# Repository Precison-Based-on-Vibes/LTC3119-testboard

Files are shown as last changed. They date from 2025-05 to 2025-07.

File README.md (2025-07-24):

# LTC3119-testboard
LTC3119 testbord is a device build to test MPPT adaptation of this DCDC converter

## Schematic

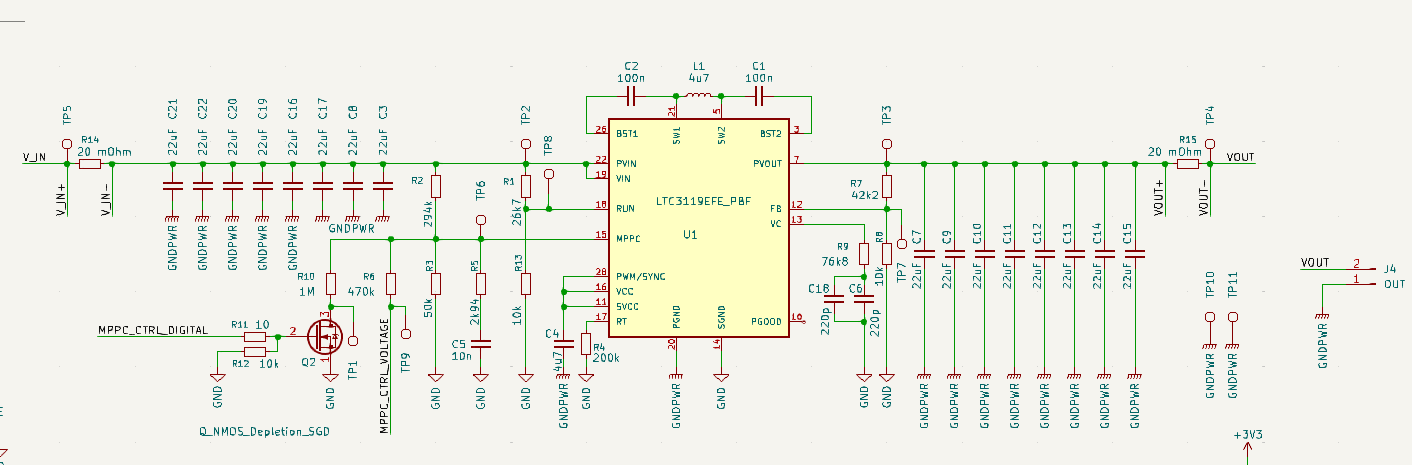
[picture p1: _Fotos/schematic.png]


## Tests Documentation

### Configuration A
- Configuration of a testbed before tests:
    - Input Capacitance: 4 x 22 uF
    - Output Capacitance: 4 x 22uF
    - MPPC Compensation: 10nF, 1k47 Ohm (C5, R5)
    - Evrything else: same as in design files

- Nominal operation - Output noice mesurment (probed directly with coaxial cable with 50 ohm terminantion on oscilosope)
    - No external load (PSU not current limited)  
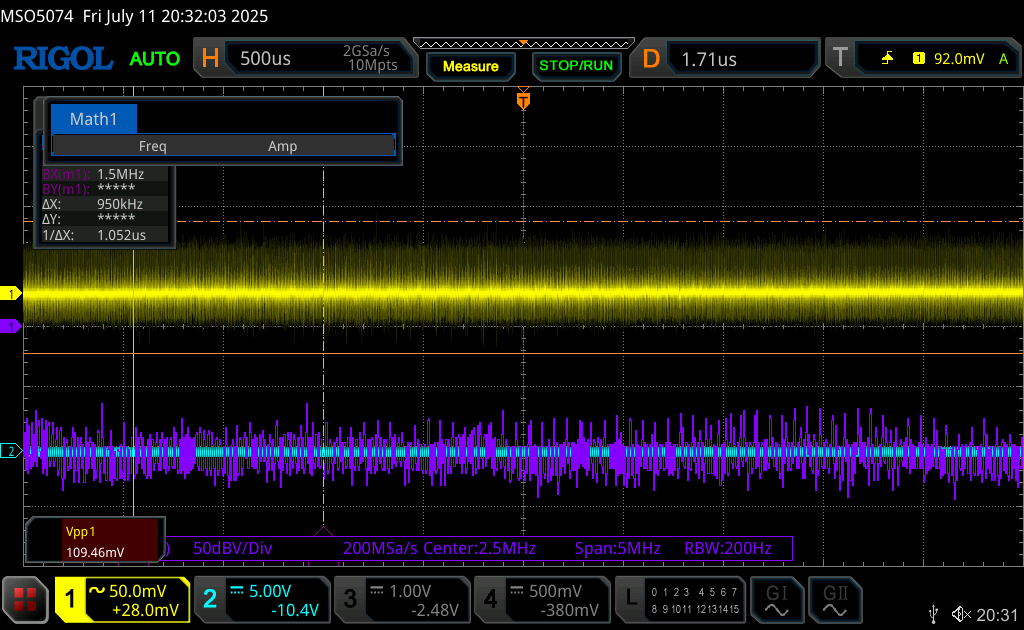
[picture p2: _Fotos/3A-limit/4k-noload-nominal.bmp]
    
    - External load 1A (PSU not current limited)  
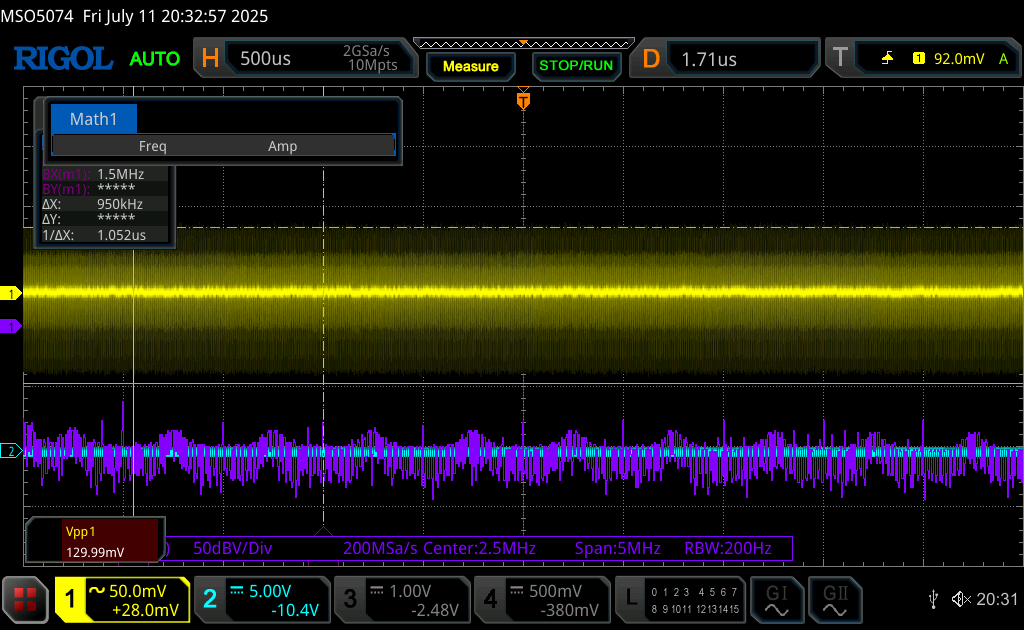
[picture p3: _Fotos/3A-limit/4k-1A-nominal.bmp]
    
    - External load 2A (PSU not current limited)  
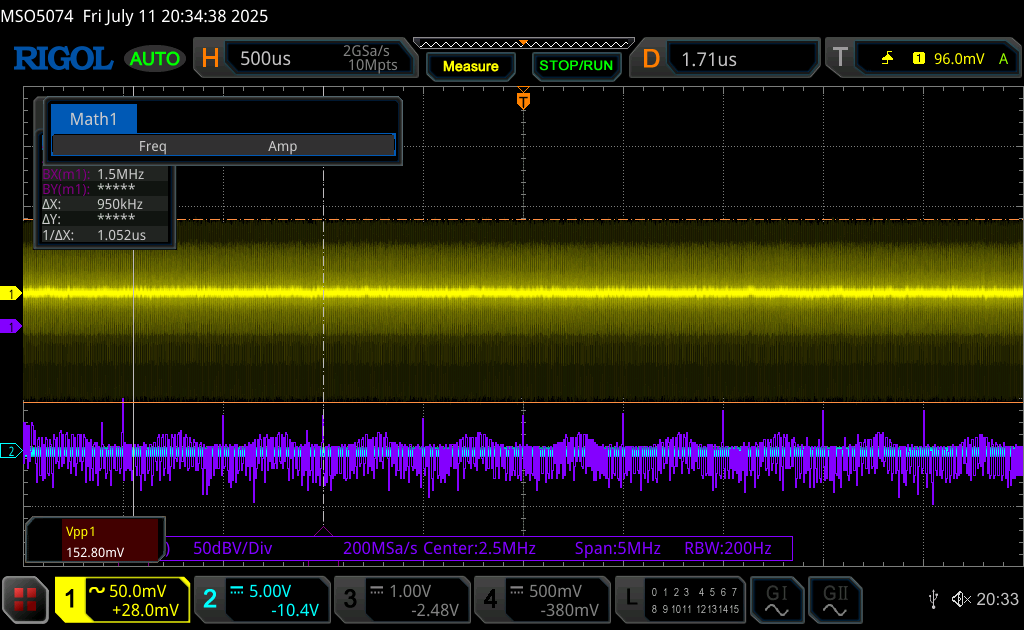
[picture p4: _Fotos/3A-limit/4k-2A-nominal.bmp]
    
    - External load 3A (PSU not current limited)  
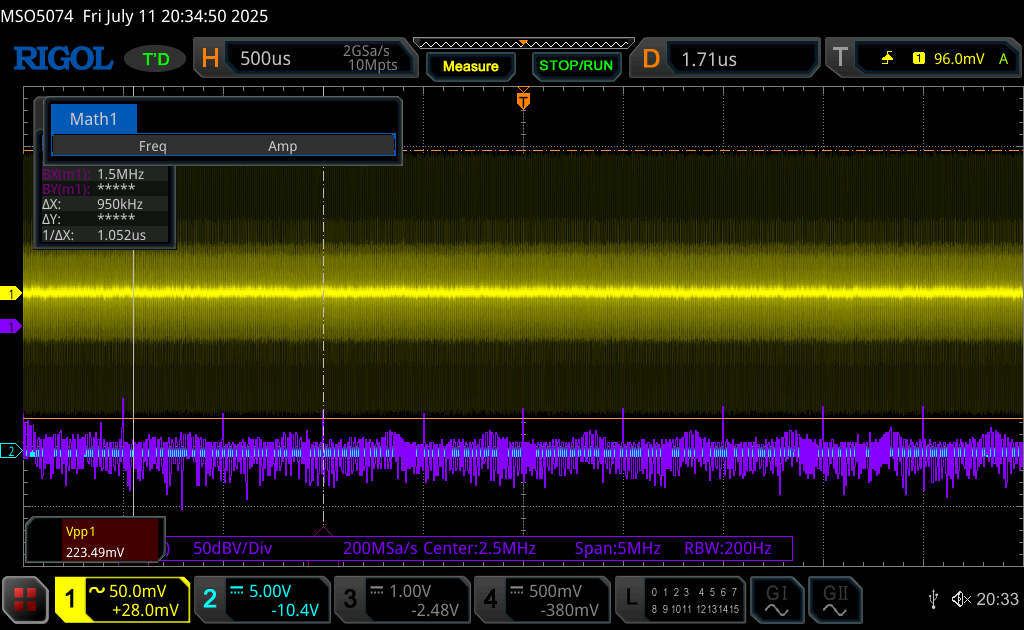
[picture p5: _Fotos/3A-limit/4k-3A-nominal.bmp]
    

- MPPC Test - Output Voltage and noice mesurment (probed directly with coaxial cable with 50 ohm terminantion on oscilosope)
    - External load 1A - Messured output voltage - 4.09 V (voltage messured on electronic load, not compensated for voltage drop on cables) (PSU limited to 1A - not active)  
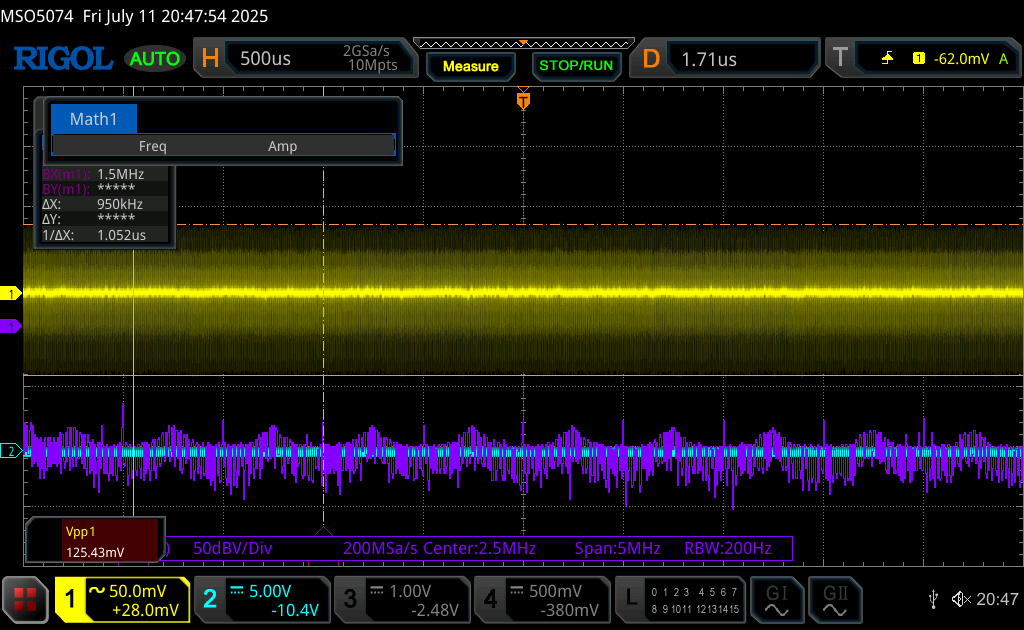
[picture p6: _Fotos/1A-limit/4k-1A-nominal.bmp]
    
    - External load 1A5 - Messured output voltage - 3.13 V (voltage messured on electronic load, not compensated for voltage drop on cables) (PSU limited to 1A - active)   
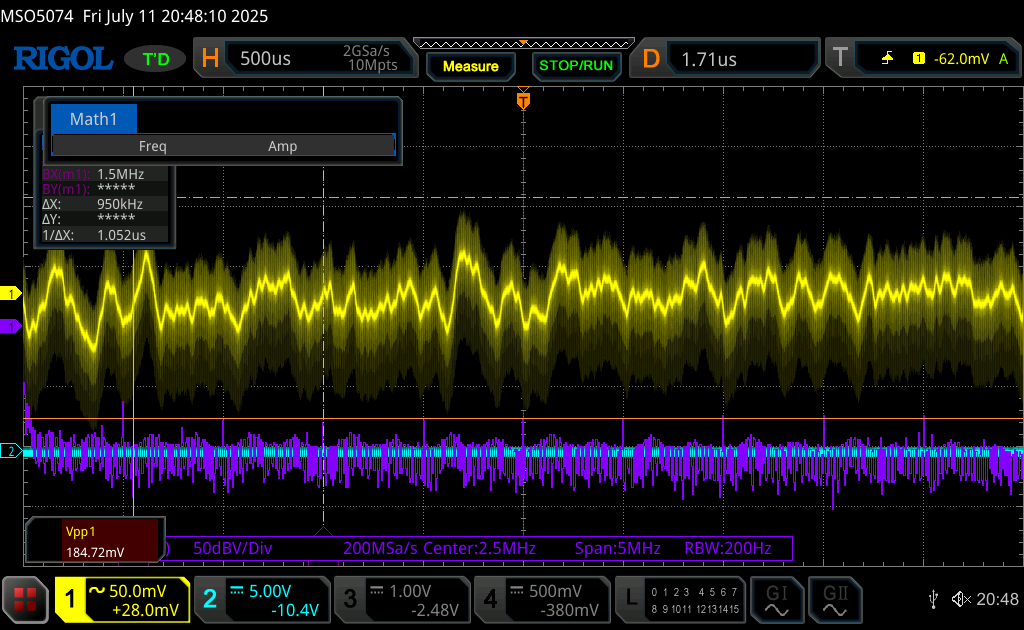
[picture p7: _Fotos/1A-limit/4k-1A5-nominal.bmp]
    
    - External load 2A - Messured output voltage - 2.25 V (voltage messured on electronic load, not compensated for voltage drop on cables) (PSU limited to 1A - active)  
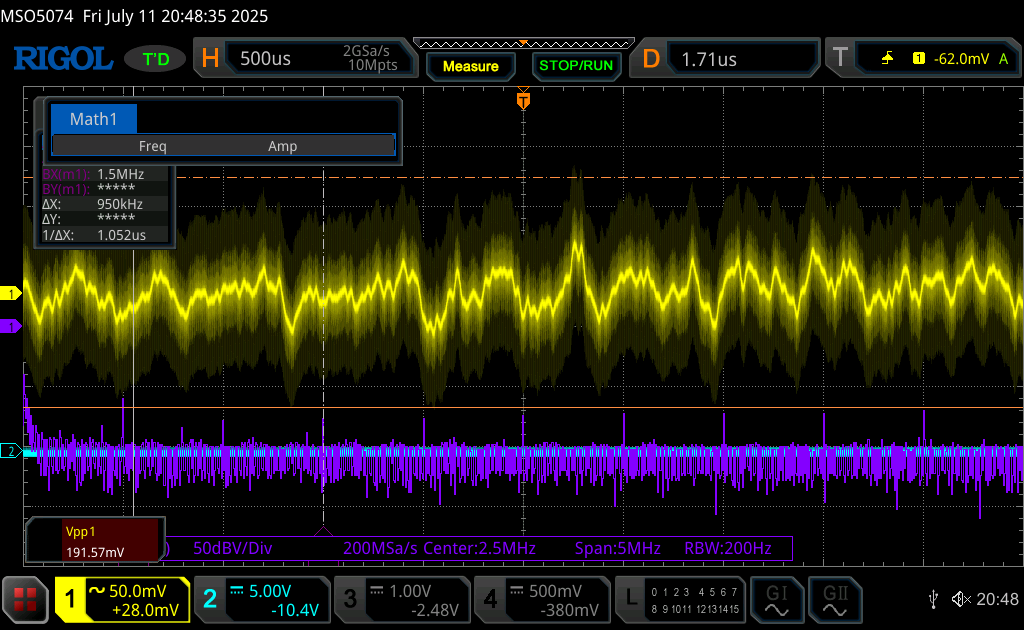
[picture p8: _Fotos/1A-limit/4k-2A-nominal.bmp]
    
    - External load 1A3 - Messured output voltage - 3.63 V (voltage messured on electronic load, not compensated for voltage drop on cables) (PSU limited to 1A - active) (IMPORTANT: FFT for low frequency noice)
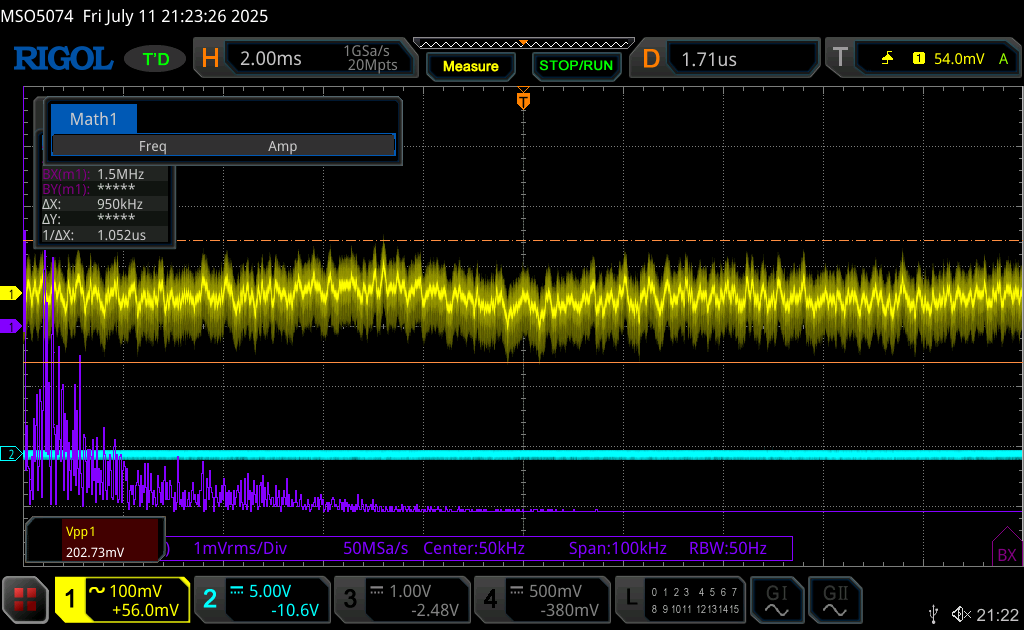
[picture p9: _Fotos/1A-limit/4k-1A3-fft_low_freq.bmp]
    

- MPPC Input voltage regulation setpoint vs control voltage  
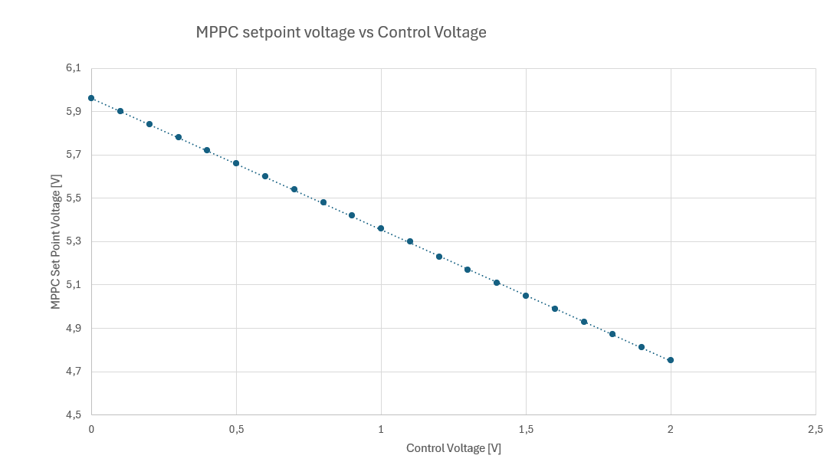
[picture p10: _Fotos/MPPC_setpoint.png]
  

### Configuration B
- Configuration of a tesbed before test:    
    - Input Capacitance: 4 x 22 uF
    - Output Capacitance: 4 x 22uF
    - MPPC Set point Components: 226k Ohm, 1M25 Ohm, 470k Ohm (R3, R2, R6)
    - MPPC Compensation: 2.2nF, 6k8 Ohm (C5, R5)
    - Evrything else: same as in design files

-  MPPC Test - Noice mesurment (probed directly with coaxial cable with 50 ohm terminantion on oscilosope)
   - External load 1A (PSU limited to 1A - not active)  
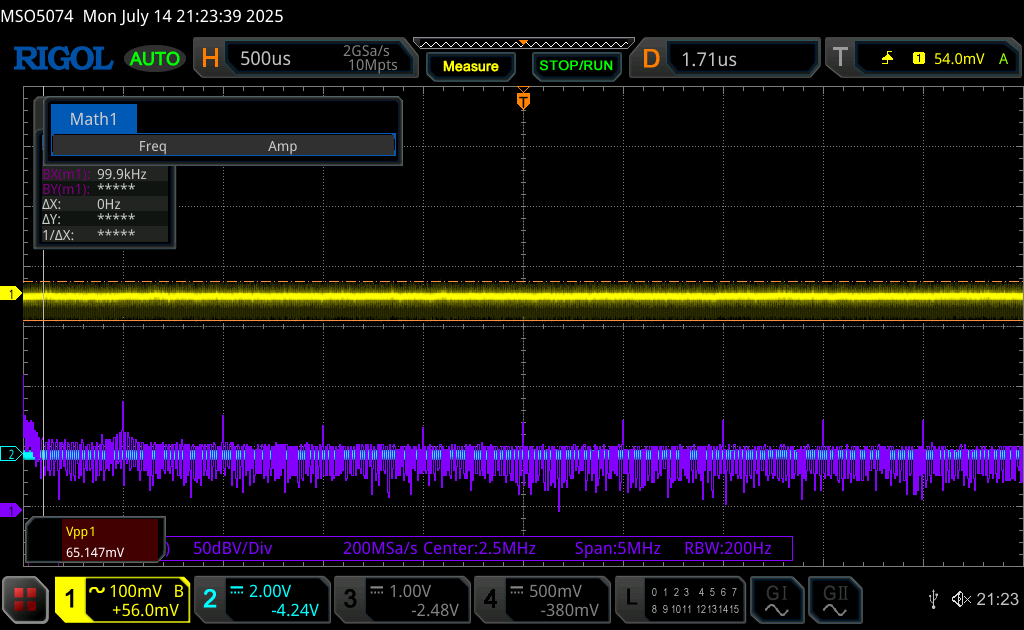
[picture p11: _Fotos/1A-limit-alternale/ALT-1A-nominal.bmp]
    
    - External load 1A5 (PSU limited to 1A - active)   
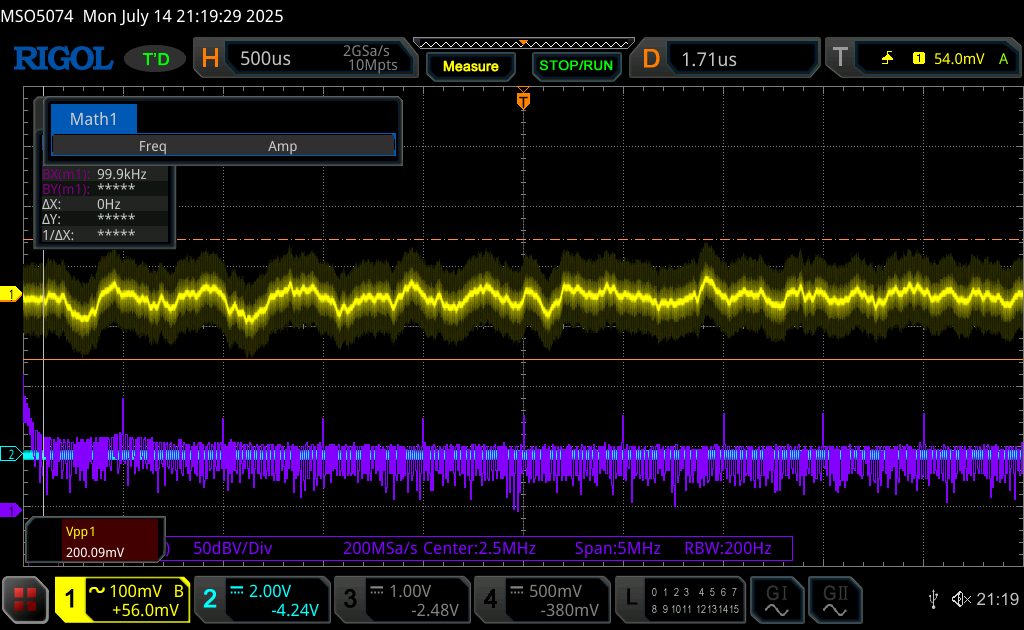
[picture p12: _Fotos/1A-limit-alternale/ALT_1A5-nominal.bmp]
    
    - External load 2A (PSU limited to 1A - active)  
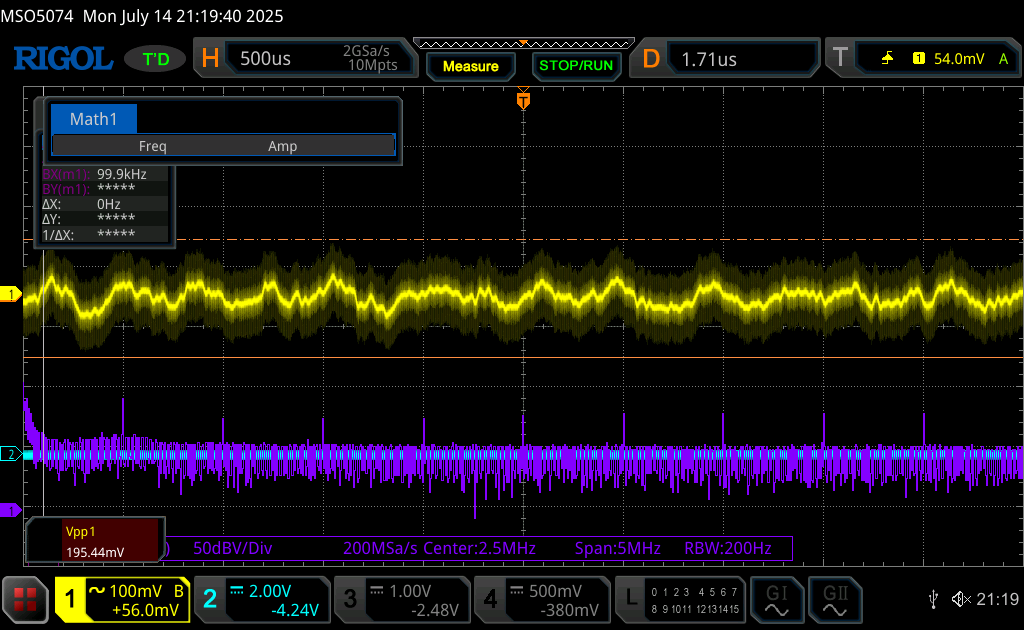
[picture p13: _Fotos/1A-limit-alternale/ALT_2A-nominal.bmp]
    
    - External load 1A3 - Messured output voltage - 3.63 V (PSU limited to 1A - active) (IMPORTANT: FFT for low frequency noice)
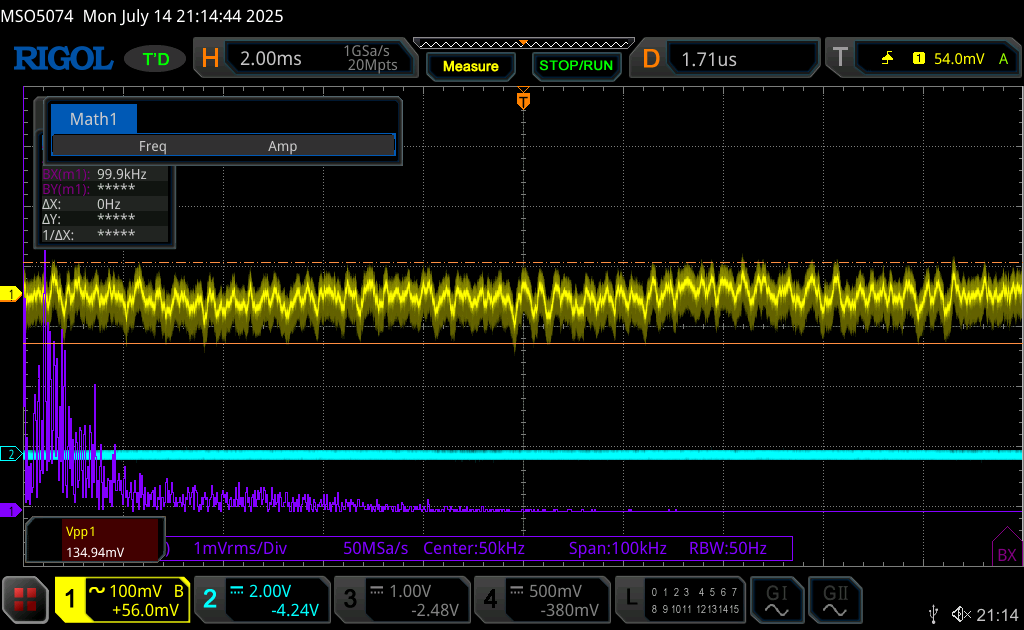
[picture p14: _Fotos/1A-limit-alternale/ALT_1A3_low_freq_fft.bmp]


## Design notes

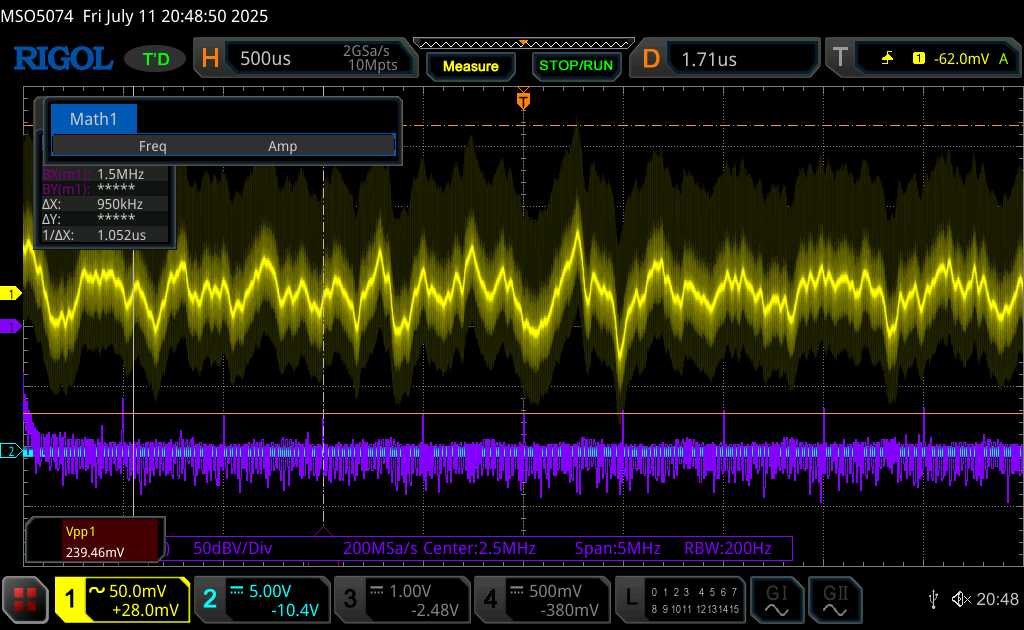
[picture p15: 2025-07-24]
_Fotos/1A-limit/4k-2A5-nominal.bmp

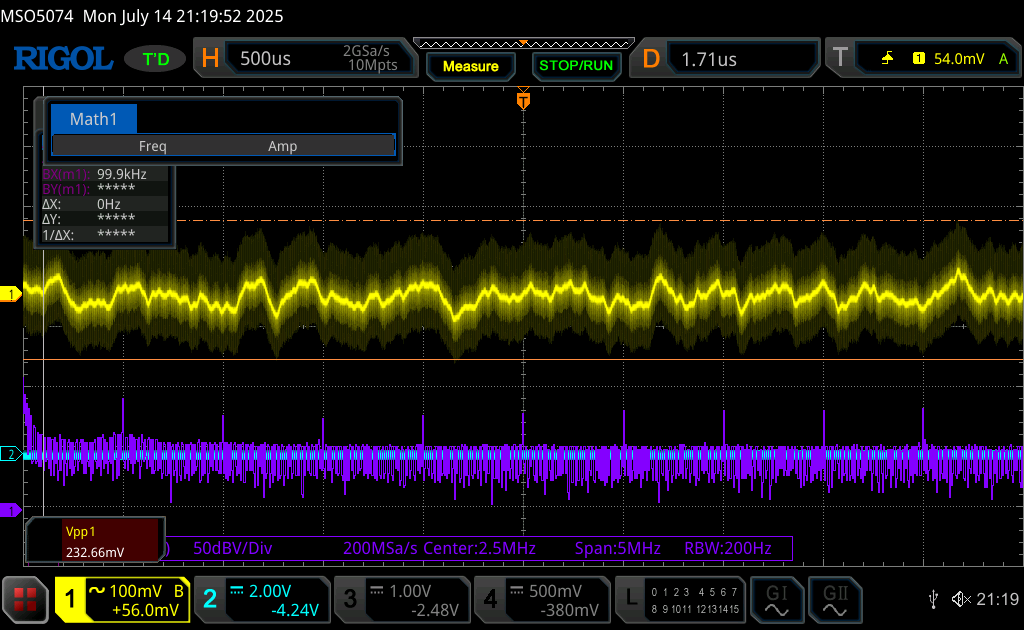
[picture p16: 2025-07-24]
_Fotos/1A-limit-alternale/ALT-2A5-nominal.bmp

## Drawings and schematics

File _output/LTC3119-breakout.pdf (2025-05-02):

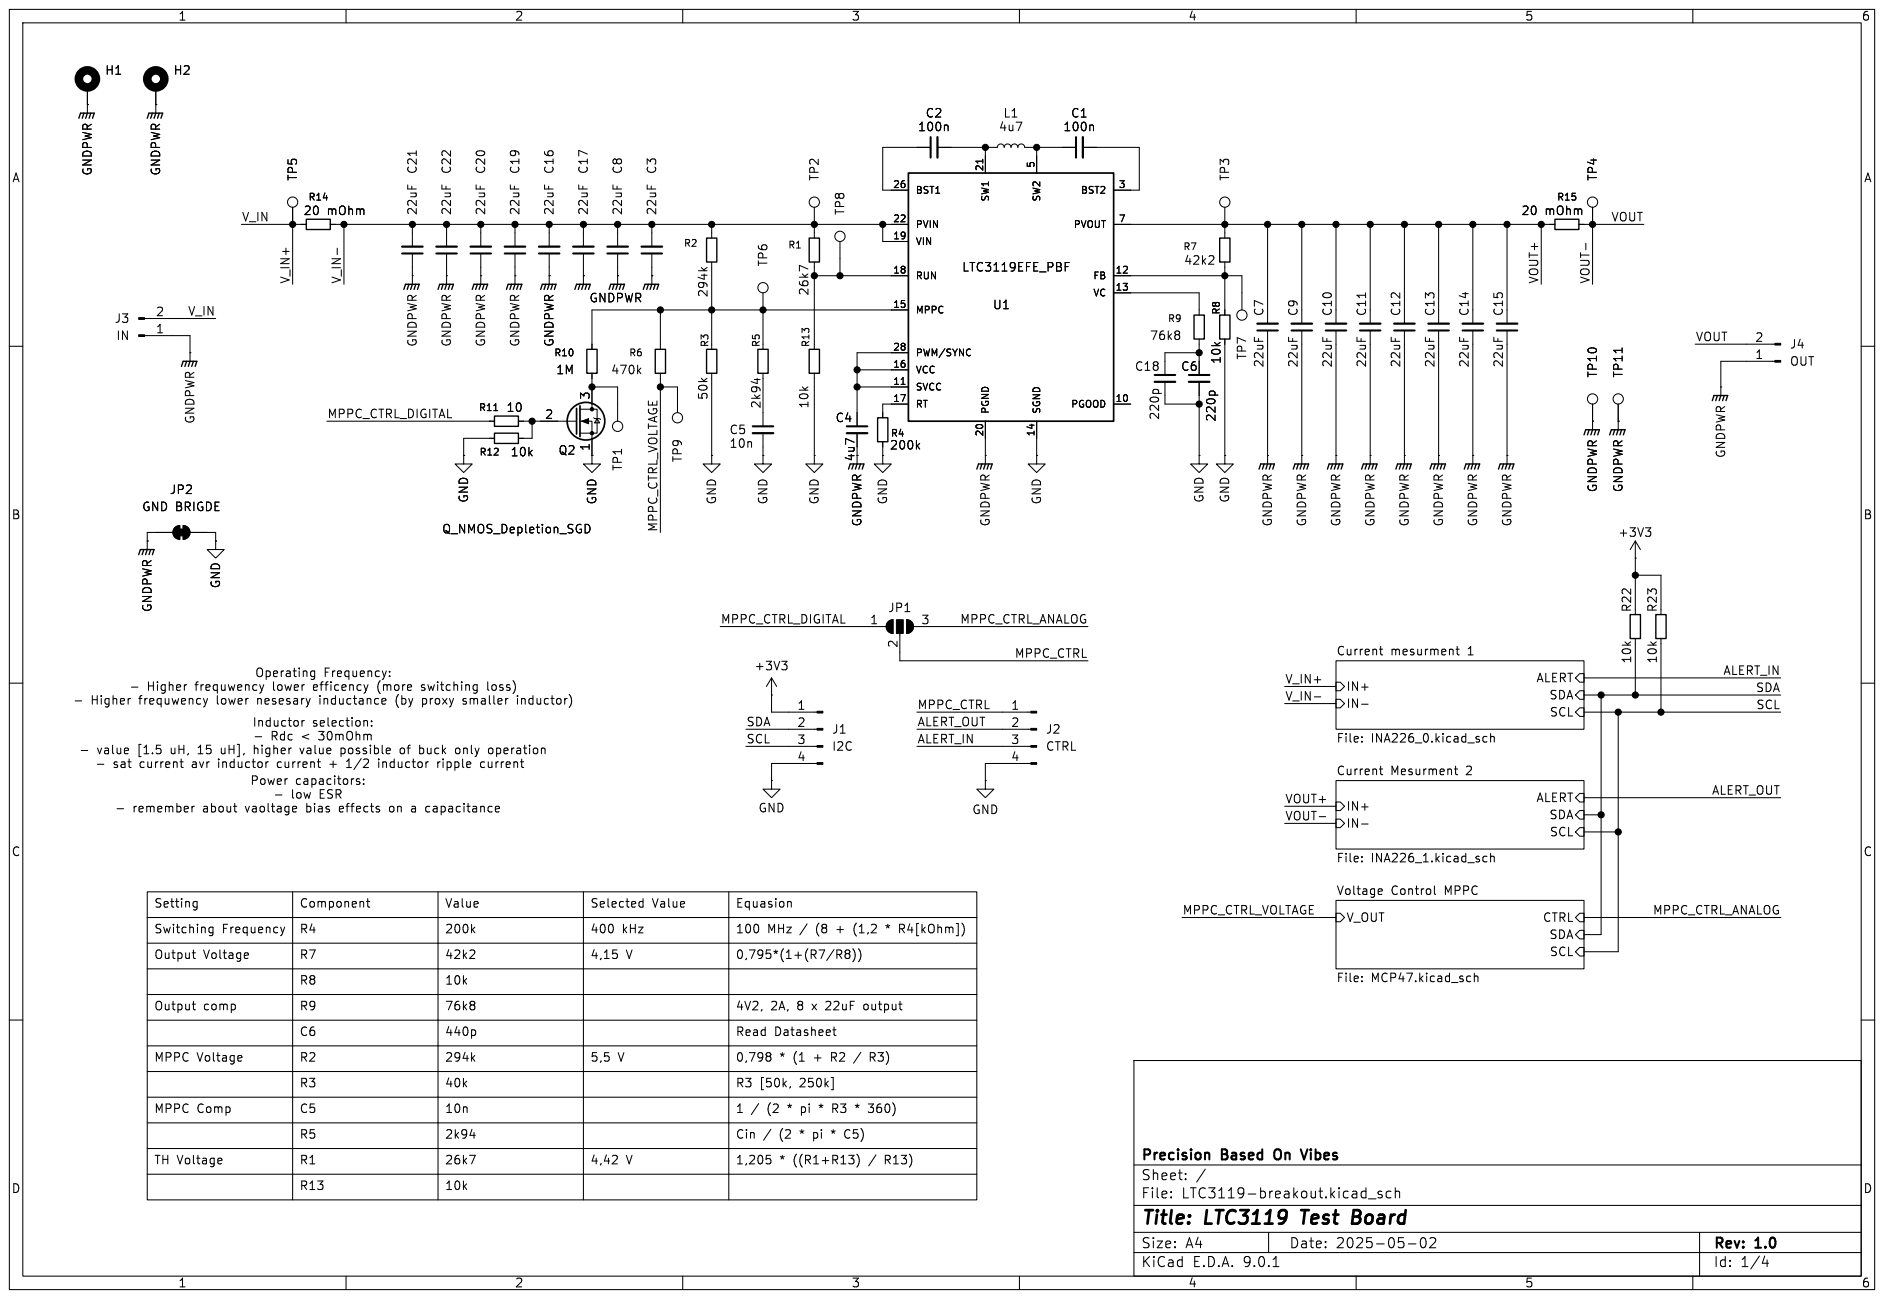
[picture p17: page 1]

5 SGND 14 BST2 3 PVOUT 7 FB 12 VC 13 PGOOD 10 C2

5 SGND 14 BST2 3 PVOUT 7 FB 12 VC 13 PGOOD 10 U1

Id: 1/4 Title: LTC3119 Test Board

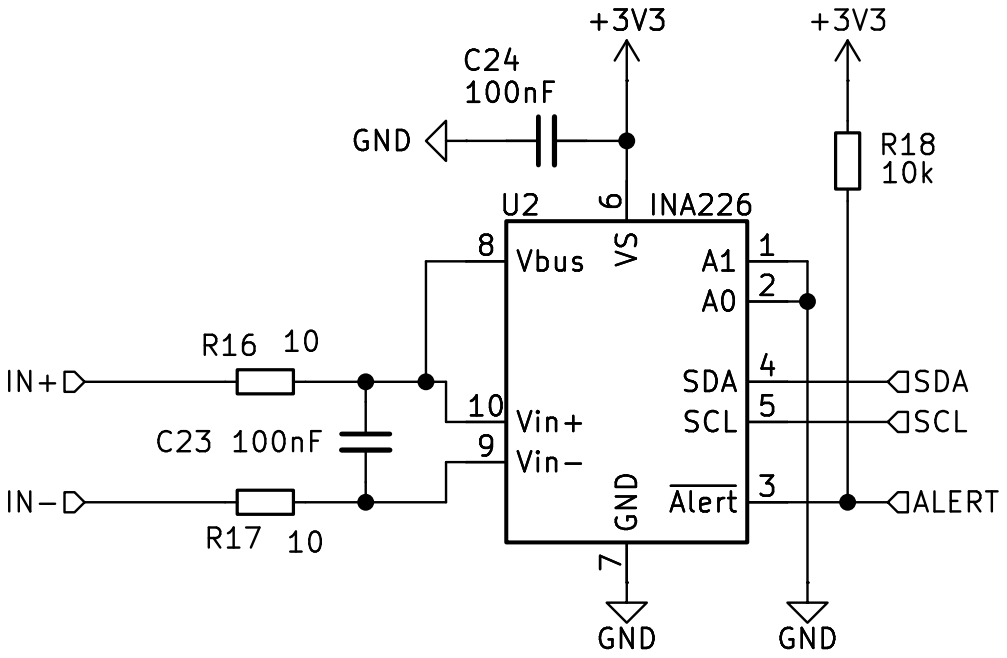
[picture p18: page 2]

7 A1 1 A0 2 SDA 4 SCL 5 ~{Alert}3 U2 INA226 +3V3 C23 100nF R17 10 R16 10 GND

7 A1 1 A0 2 SDA 4 SCL 5 ~{Alert}3 GND GND GND

Id: 2/4 Title: LTC3119 Test Board

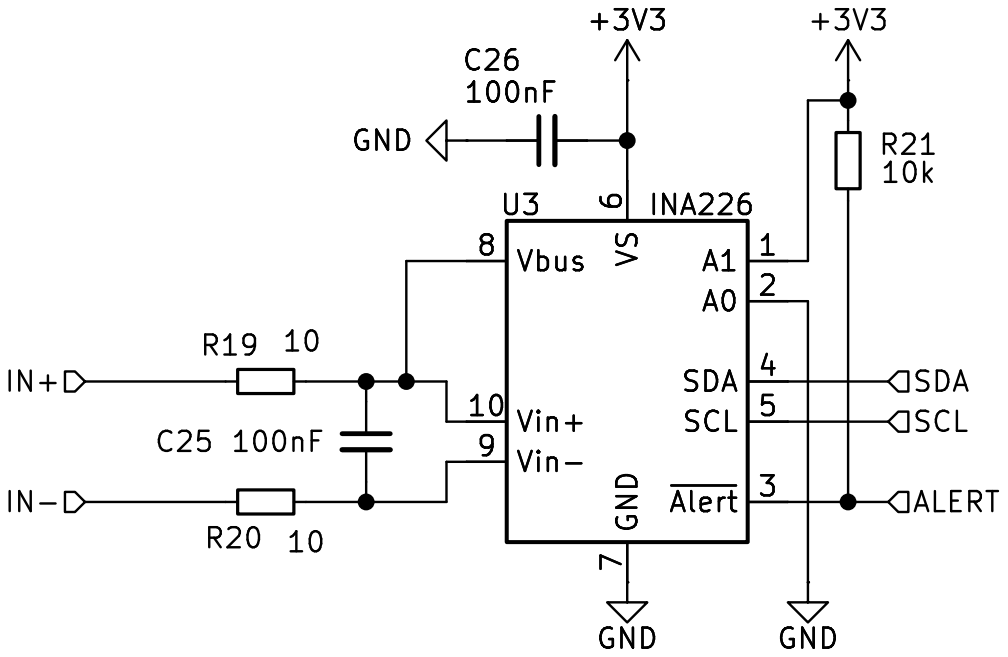
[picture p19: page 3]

7 A1 1 A0 2 SDA 4 SCL 5 ~{Alert}3 GND

Id: 3/4 Title: LTC3119 Test Board

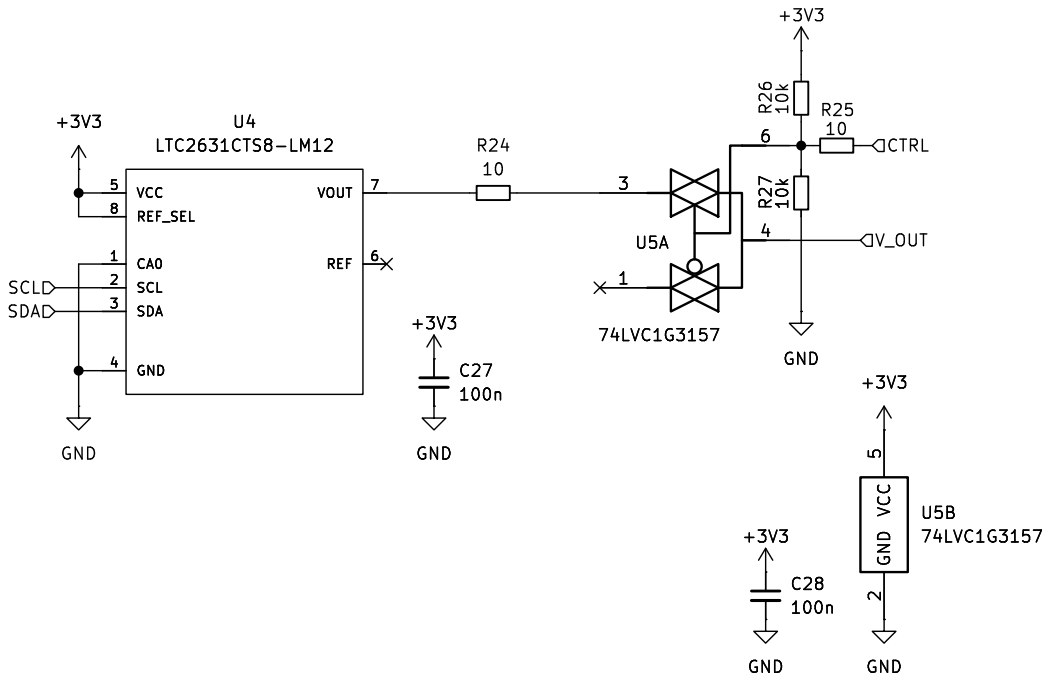
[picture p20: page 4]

Id: 4/4 Title: LTC3119 Test Board

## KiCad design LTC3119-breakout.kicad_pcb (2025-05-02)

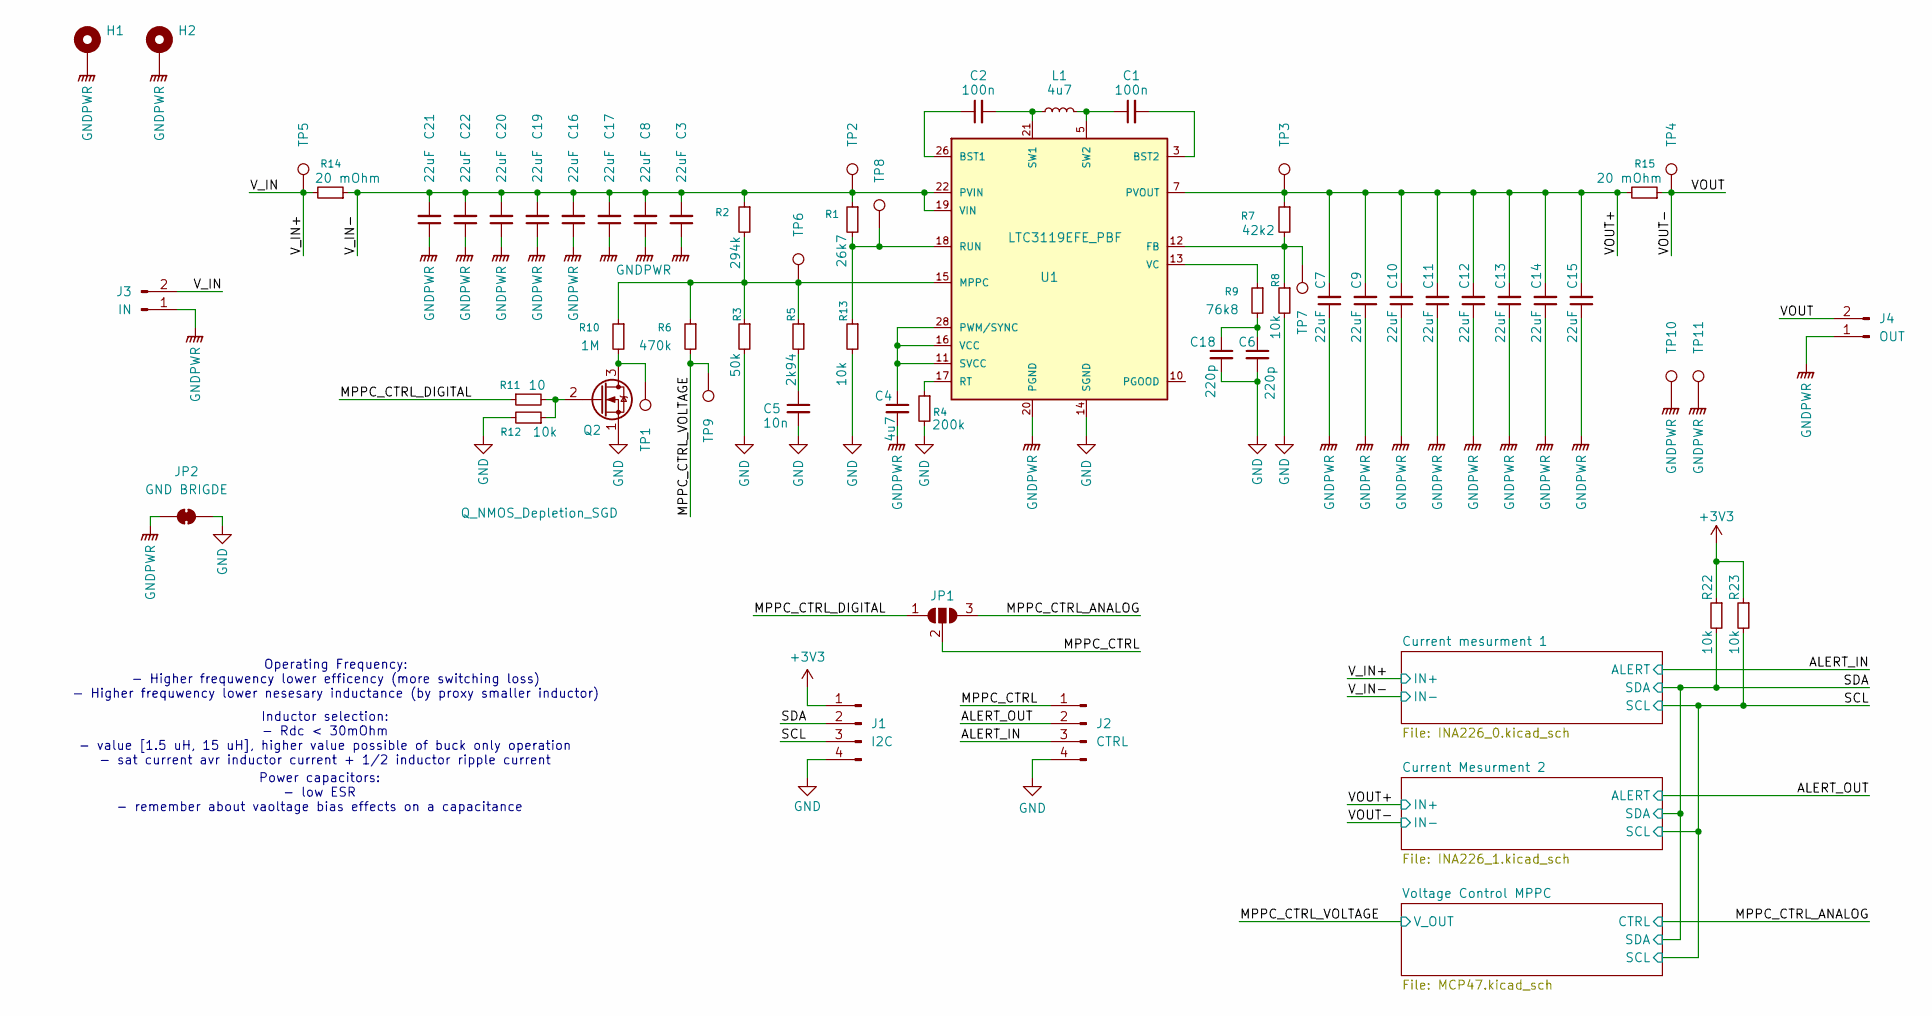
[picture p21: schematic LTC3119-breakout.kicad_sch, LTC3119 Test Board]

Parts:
C1, C2: 100n; C_0805_2012Metric_Pad1.18x1.45mm_HandSolder
C3, C7, C8, C9, C10, C11, C12, C13, C14, C15, C16, C17, C19, C20, C21, C22: 22uF; C_1210_3225Metric_Pad1.33x2.70mm_HandSolder
C4: 4u7; C_0805_2012Metric_Pad1.18x1.45mm_HandSolder
C5: 10n; C_0805_2012Metric_Pad1.18x1.45mm_HandSolder
C6, C18: 220p; C_0805_2012Metric_Pad1.18x1.45mm_HandSolder
H1, H2: MountingHole_Pad; MountingHole_3.2mm_M3_DIN965_Pad
J1: I2C; PinHeader_1x04_P2.54mm_Vertical
J2: CTRL; PinHeader_1x04_P2.54mm_Vertical
J3: IN; Molex_Pico-Lock_205338-0002_1x02-1MP_P2.00mm_Horizontal
J4: OUT; Molex_Pico-Lock_205338-0002_1x02-1MP_P2.00mm_Horizontal
JP1: SolderJumper_3_Open; SolderJumper-3_P1.3mm_Open_Pad1.0x1.5mm
JP2: GND BRIGDE; SolderJumper-2_P1.3mm_Bridged_Pad1.0x1.5mm
L1: 4u7; SRR1280A101M
Q2: Q_NMOS_Depletion_SGD; SOT-23_Handsoldering
R1: 26k7; R_0805_2012Metric_Pad1.20x1.40mm_HandSolder
R2: 294k; R_0805_2012Metric_Pad1.20x1.40mm_HandSolder
R3: 50k; R_0805_2012Metric_Pad1.20x1.40mm_HandSolder
R4: 200k; R_0805_2012Metric_Pad1.20x1.40mm_HandSolder
R5: 2k94; R_0805_2012Metric_Pad1.20x1.40mm_HandSolder
R6: 470k; R_0805_2012Metric_Pad1.20x1.40mm_HandSolder
R7: 42k2; R_0805_2012Metric_Pad1.20x1.40mm_HandSolder
R8, R12, R13, R22, R23: 10k; R_0805_2012Metric_Pad1.20x1.40mm_HandSolder
R9: 76k8; R_0805_2012Metric_Pad1.20x1.40mm_HandSolder
R10: 1M; R_0805_2012Metric_Pad1.20x1.40mm_HandSolder
R11: 10; R_0805_2012Metric_Pad1.20x1.40mm_HandSolder
R14, R15: 20 mOhm; R_0805_2012Metric_Pad1.20x1.40mm_HandSolder
TP1, TP2, TP3, TP4, TP5, TP6, TP7, TP8, TP9, TP10, TP11: TestPoint; TestPoint_Pad_D1.0mm
U1: LTC3119EFE_PBF; SOP65P640X120-29N; PARTREV B

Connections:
+3V3: J1.1, R22.1, R23.1; also elsewhere on the board
/ALERT_IN: J2.3; also elsewhere on the board
/ALERT_OUT: J2.2; also elsewhere on the board
/MPPC_CTRL: J2.1, JP1.2 (C)
/MPPC_CTRL_ANALOG: JP1.3 (B); also elsewhere on the board
/MPPC_CTRL_DIGITAL: JP1.1 (A), R11.1
/MPPC_CTRL_VOLTAGE: R6.2, TP9.1; also elsewhere on the board
/SCL: J1.3, R23.2; also elsewhere on the board
/SDA: J1.2, R22.2; also elsewhere on the board
/VOUT: J4.2, R15.1, TP4.1; also elsewhere on the board
/VOUT+: C7.2, C9.2, C10.2, C11.2, C12.2, C13.2, C14.2, C15.2, R7.1, R15.2, TP3.1, U1.6 (PVOUT), U1.7 (PVOUT); also elsewhere on the board
/V_IN: J3.2, R14.2, TP5.1; also elsewhere on the board
/V_IN-: C3.2, C8.2, C16.2, C17.2, C19.2, C20.2, C21.2, C22.2, R1.1, R2.1, R14.1, TP2.1, U1.19 (VIN), U1.22 (PVIN), U1.23 (PVIN); also elsewhere on the board
GND: C5.2, C6.2, C18.2, J1.4, J2.4, JP2.2 (B), Q2.1 (S), R3.2, R4.2, R8.2, R12.2, R13.2, U1.14 (SGND); also elsewhere on the board
GNDPWR: C3.1, C4.2, C7.1, C8.1, C9.1, C10.1, C11.1, C12.1, C13.1, C14.1, C15.1, C16.1, C17.1, C19.1, C20.1, C21.1, C22.1, H1.1, H2.1, J3.1, J4.1, JP2.1 (A), TP10.1, TP11.1, U1.4 (PGND), U1.9 (PGND), U1.20 (PGND), U1.25 (PGND), U1.29 (PGND)
unnamed: C1.1, L1.2, U1.5 (SW2), U1.8 (SW2)
unnamed: C2.2, L1.1, U1.21 (SW1), U1.24 (SW1)
unnamed: C5.1, R5.2
unnamed: C6.1, C18.1, R9.2
unnamed: Q2.3 (D), R10.2, TP1.1
unnamed: Q2.2 (G), R11.2, R12.1
unnamed: C2.1, U1.26 (BST1)
unnamed: C1.2, U1.3 (BST2)
unnamed: R7.2, R8.1, TP7.1, U1.12 (FB)
unnamed: R2.2, R3.1, R5.1, R6.1, R10.1, TP6.1, U1.15 (MPPC)
unnamed: C4.1, U1.11 (SVCC), U1.16 (VCC), U1.28 (PWM/SYNC)
unnamed: R4.1, U1.17 (RT)
unnamed: R1.2, R13.1, TP8.1, U1.18 (RUN)
unnamed: R9.1, U1.13 (VC)

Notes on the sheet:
Power capacitors: - low ESR - remember about vaoltage bias effects on a capacitance
Operating Frequency: - Higher frequwency lower efficency (more switching loss) - Higher frequwency lower nesesary inductance (by proxy smaller inductor)
Inductor selection: - Rdc < 30mOhm - value [1.5 uH, 15 uH], higher value possible of buck only operation - sat current avr inductor current + 1/2 inductor ripple current

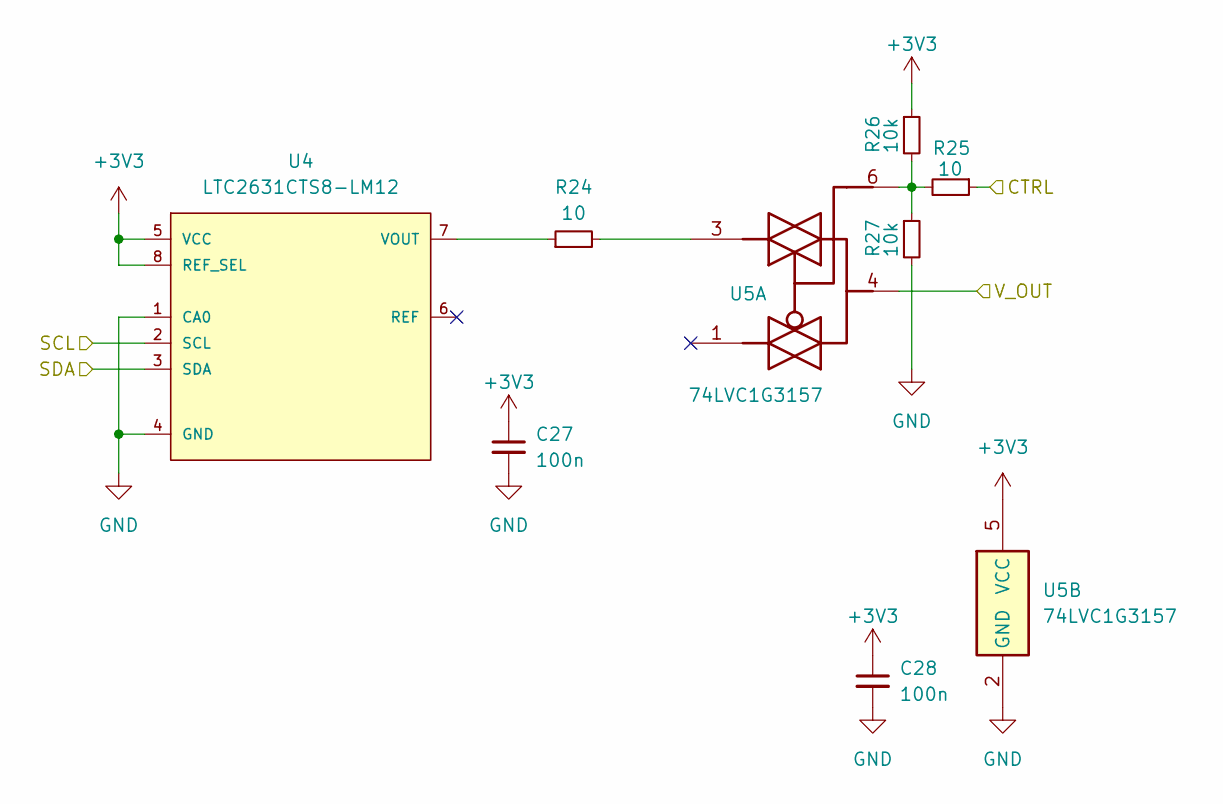
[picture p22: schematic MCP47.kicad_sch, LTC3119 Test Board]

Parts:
C27, C28: 100n; C_0805_2012Metric_Pad1.18x1.45mm_HandSolder
R24, R25: 10; R_0805_2012Metric_Pad1.20x1.40mm_HandSolder
R26, R27: 10k; R_0805_2012Metric_Pad1.20x1.40mm_HandSolder
U4: LTC2631CTS8-LM12; TSOT-23-8_HandSoldering
U5: 74LVC1G3157; SOT-23-6_Handsoldering

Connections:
+3V3: C27.1, C28.1, R26.1, U4.5 (VCC), U4.8 (REF_SEL), U5.5 (VCC); also elsewhere on the board
/MPPC_CTRL_ANALOG: R25.1; also elsewhere on the board
/MPPC_CTRL_VOLTAGE: U5.4; also elsewhere on the board
/SCL: U4.2 (SCL); also elsewhere on the board
/SDA: U4.3 (SDA); also elsewhere on the board
GND: C27.2, C28.2, R27.2, U4.1 (CA0), U4.4 (GND), U5.2 (GND); also elsewhere on the board
unnamed: R24.2, U5.3
unnamed: R25.2, R26.2, R27.1, U5.6
unnamed: R24.1, U4.7 (VOUT)

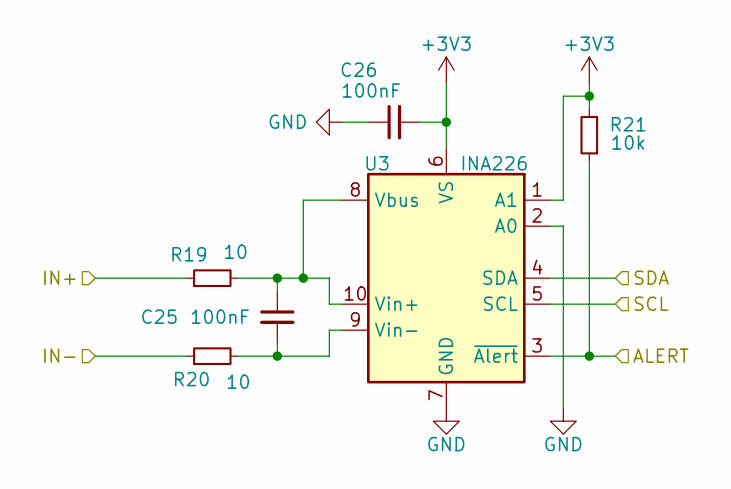
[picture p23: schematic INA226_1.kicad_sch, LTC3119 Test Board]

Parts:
C25, C26: 100nF; C_0805_2012Metric_Pad1.18x1.45mm_HandSolder
R19, R20: 10; R_0805_2012Metric_Pad1.20x1.40mm_HandSolder
R21: 10k; R_0805_2012Metric_Pad1.20x1.40mm_HandSolder
U3: INA226; VSSOP-10_3x3mm_P0.5mm

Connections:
+3V3: C26.2, R21.2, U3.1 (A1), U3.6 (VS); also elsewhere on the board
/ALERT_OUT: R21.1, U3.3 (~Alert); also elsewhere on the board
/SCL: U3.5 (SCL); also elsewhere on the board
/SDA: U3.4 (SDA); also elsewhere on the board
/VOUT: R20.1; also elsewhere on the board
/VOUT+: R19.1; also elsewhere on the board
GND: C26.1, U3.2 (A0), U3.7 (GND); also elsewhere on the board
unnamed: C25.1, R19.2, U3.8 (Vbus), U3.10 (Vin+)
unnamed: C25.2, R20.2, U3.9 (Vin-)

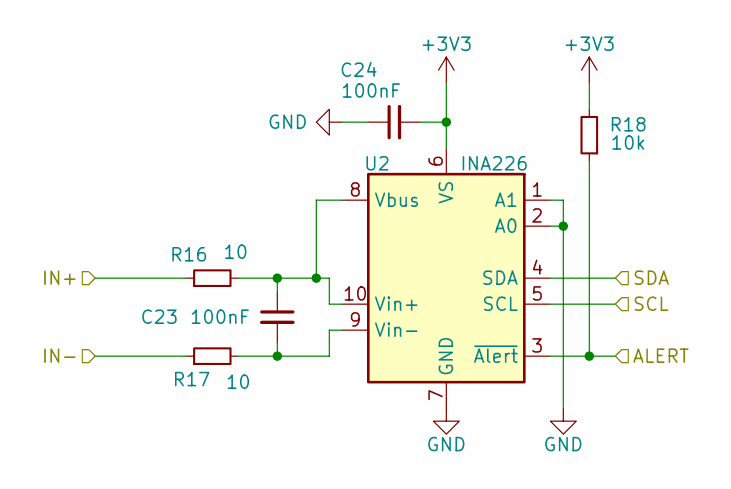
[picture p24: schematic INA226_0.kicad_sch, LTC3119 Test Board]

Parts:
C23, C24: 100nF; C_0805_2012Metric_Pad1.18x1.45mm_HandSolder
R16, R17: 10; R_0805_2012Metric_Pad1.20x1.40mm_HandSolder
R18: 10k; R_0805_2012Metric_Pad1.20x1.40mm_HandSolder
U2: INA226; VSSOP-10_3x3mm_P0.5mm

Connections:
+3V3: C24.2, R18.2, U2.6 (VS); also elsewhere on the board
/ALERT_IN: R18.1, U2.3 (~Alert); also elsewhere on the board
/SCL: U2.5 (SCL); also elsewhere on the board
/SDA: U2.4 (SDA); also elsewhere on the board
/V_IN: R16.1; also elsewhere on the board
/V_IN-: R17.1; also elsewhere on the board
GND: C24.1, U2.1 (A1), U2.2 (A0), U2.7 (GND); also elsewhere on the board
unnamed: C23.1, R16.2, U2.8 (Vbus), U2.10 (Vin+)
unnamed: C23.2, R17.2, U2.9 (Vin-)

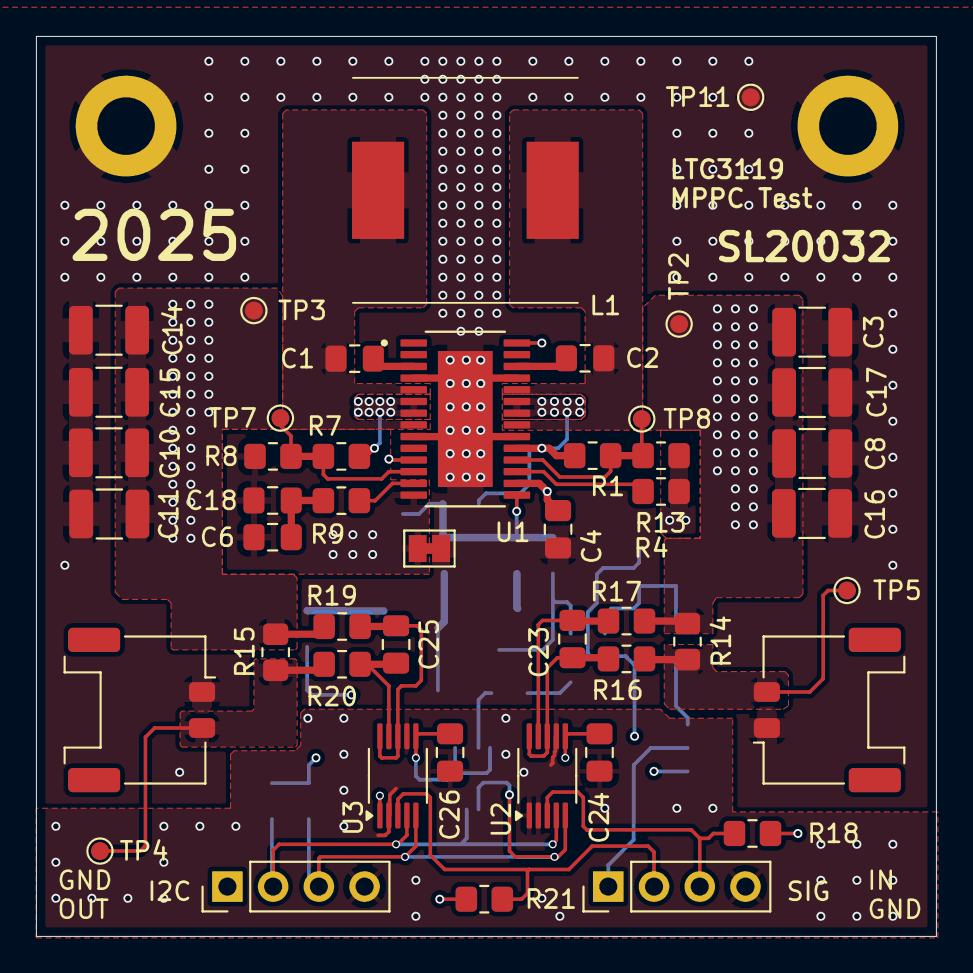
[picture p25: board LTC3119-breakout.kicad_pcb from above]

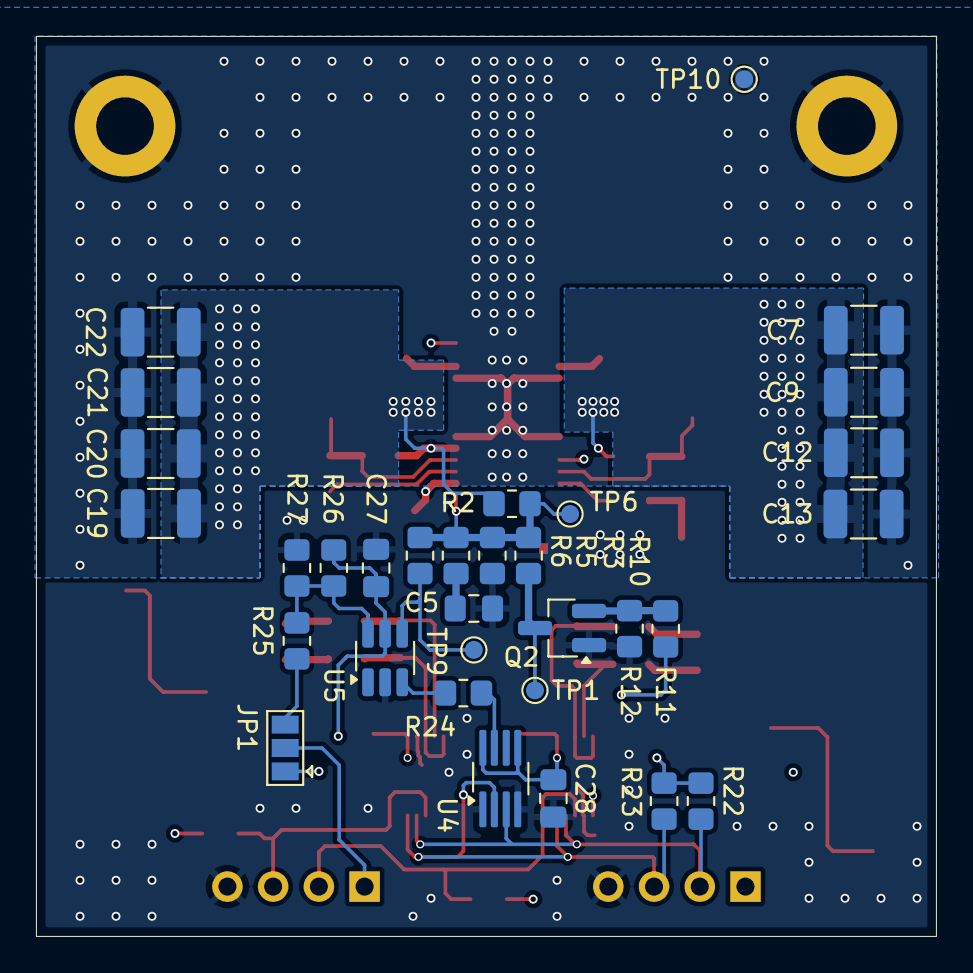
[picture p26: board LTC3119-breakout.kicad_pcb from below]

Board: 4 copper layers, 50.0 x 50.0 mm, 81 parts (32 on the bottom side), 36 nets.
